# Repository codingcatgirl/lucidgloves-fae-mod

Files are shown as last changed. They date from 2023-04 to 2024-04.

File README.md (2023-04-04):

# LucidGloves Fae Mod

This repository contains files and instructions how to build the **LucidglovesFae Mod**, a mod of the
**[Lucidgloves Prototype 5](https://github.com/LucidVR/lucidgloves/tree/proto5) by Lucas VRTech**.

<p>
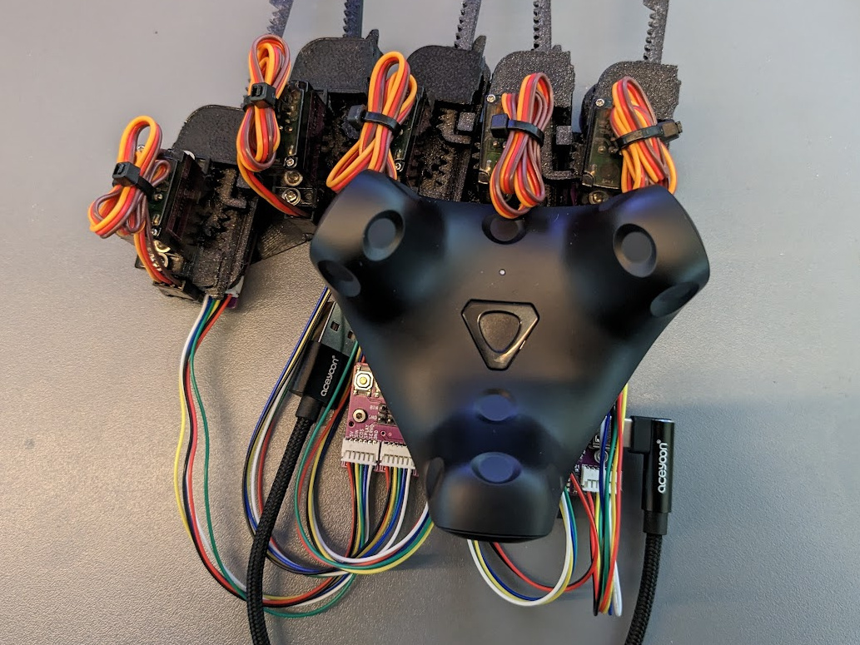
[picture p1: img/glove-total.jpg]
  
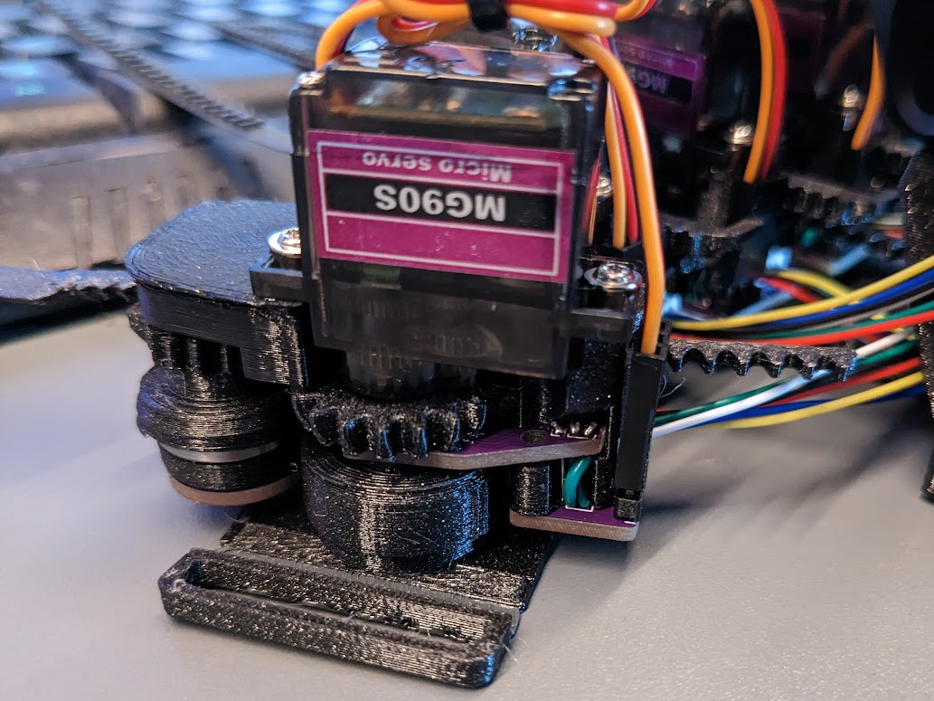
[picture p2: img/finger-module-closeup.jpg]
     
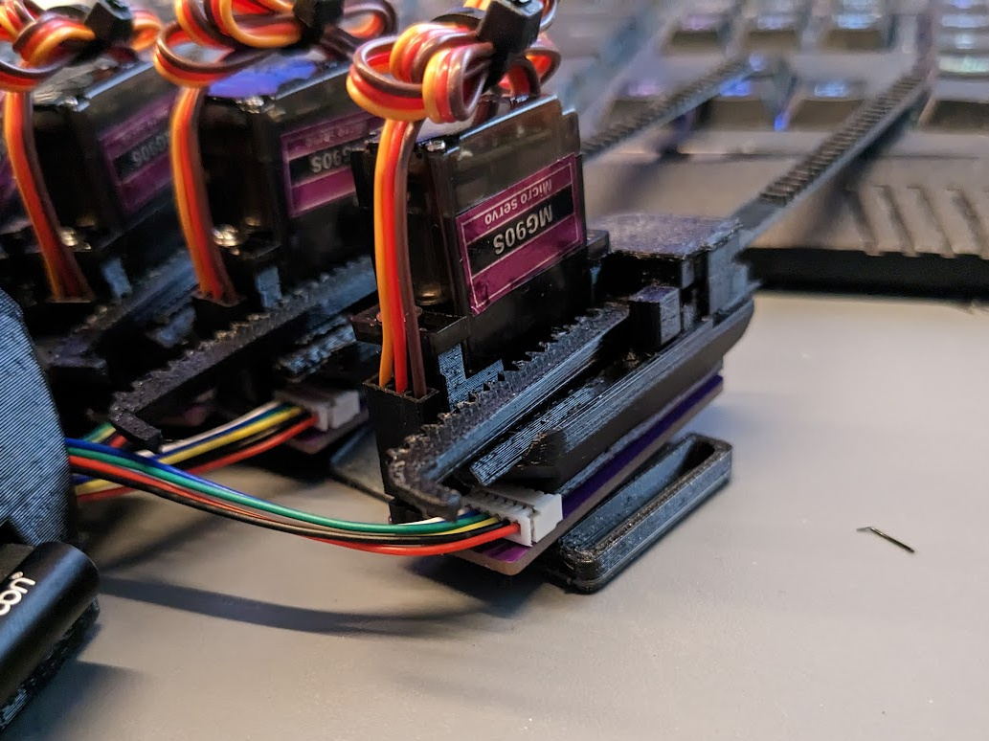
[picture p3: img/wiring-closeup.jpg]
  
</p>

<p>
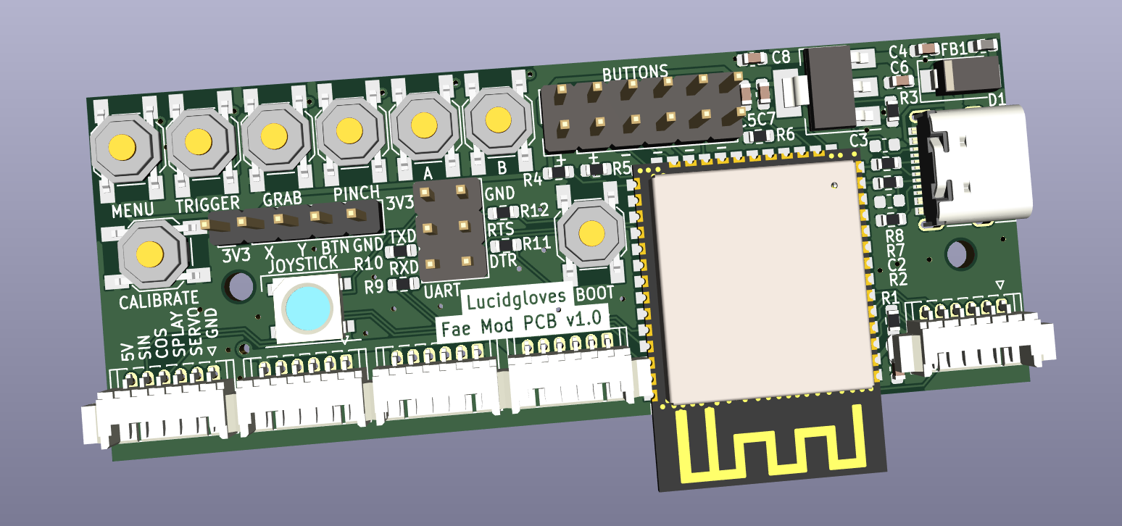
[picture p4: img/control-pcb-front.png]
  
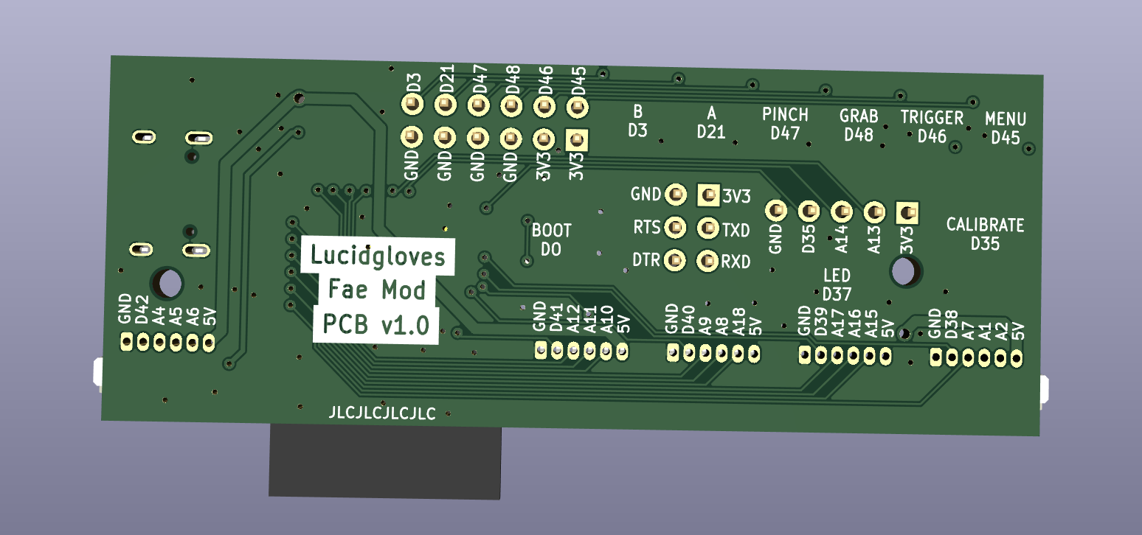
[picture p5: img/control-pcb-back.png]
  
</p>

The mod presently consists of 4 features that can, in theory, be used seperately:

* Custom PCBs to greatly simplify the wiring and provide a compact control PCB featuring an ESP32-S3 chip and 
  most notably no need for a multiplexer chip. With the files provided they can be ordered directly from
  [JLCPCB](https://jlcpcb.com/) including most of the assembly. 
* A modified sensor module that prints without supports and fits the new PCBs. It can also be used without the new PCBs.
* A new tracker mount that includes space for the control PCB. It can also be used without the new PCBs.
* A two-material version of the rigid mount, that allows you to print part of it with flexible filament (TPU) so it
  flexes more nicely where it needs to. It can be used without the other parts of this mod. It can also be printed using
  a non-multi-material printer. 

## Cost

The additional parts, including the custom PCBs and shipping, will set you back ~$30 per glove for 2 gloves, or 
$20 per glove for 4 gloves. The reason for the massive price difference is that JLCPCB manufactures PCBs in multiples
of five, so you will order at least 5 control PCBs. You can have them only assemble 2, but the price
difference would be about $1. For the finger PCBs, the price barely increases if you order enough for 20 fingers instead
of 10 fingers. So, simply put: You might as well order enough parts for 4 gloves, and split the cost with a friend :)

Keep in mind this comes on top of the cost for the other parts you need for prototype 5 anyway, but you will not need 
the ESP dev module or the multiplexer chip, which will save you about $6-$7 per glove. You will also not need additional
cables as they are all included. In my opinion, the reduced hassle alone is worth the cost.

At the time of writing this, the cost of parts to build the LucidGloves Fae Mod including 3D printing filament and
all parts, according to my calculations, comes down to ~$60 per glove for 2 gloves and ~$40 per glove for 4 gloves.

Don't forget that you will still need to buy a SteamVR tracker of your choice, a USB cable and a Powerbank for each
glove thogh, of course.  

## Important caveat

**The ESP32-S3 chip does not support BluetoothSerial. This means that, presently, the gloves can only
be connected using a wired USB connection.** The chip itself supports both Bluetooth Low Energy and WiFi for
communication, neither of these are currently implemented in the firmware or the 
[opengloves driver](https://github.com/LucidVR/opengloves-driver), though there seem to be plans to support
BLE for communication in the future.

If you're a developer and feel like implementing communication via WiFi/TCP/UDP or Bluetooth Low Energy in the
oopengloves driver and submit a pull request to it, i'm sure it would be appreciated by the community.
I don't have enough experience with software development on windows to do it myself. However, i am experienced
with firmware development and if someone added the support to the opengloves driver, i would probably be up to
implementing the other side of it for the firmware.

## Instructions

- [Ordering the parts needed](docs/ordering_parts.md)
- [3D Printing the modified parts](docs/3d_printing.md)
- [Assembling the modified parts](docs/assembly.md)
- [Modifying the firmware](docs/firmware.md)

## Contributing

Feedback is always welcome.

If you have questions that are about the specific of this mod, feel free to use the issue tracker. If you have questions
about the LucidGloves in general and assembly or setup steps that are not different for this mod, please stick to the 
official support channels of the original LucidGloves.

If you find an error somewhere or see a way to improve the documentation, feel free to open an issue or a pull request.

It sure would be nice if the instructions had some screenshots and images in then. If you feel like it, make some while
you follow along with the instructions and submit them to this repo, ideally using a pull request :)

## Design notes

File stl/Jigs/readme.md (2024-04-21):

# Soldering Jigs

## Prep
You should have the jst connectors soldered to your larger boards 

You will need one each of Jig 1 and Jig 2, and two of Jig 3.

Screw a spare of the larger board to Jig 1, then attach one of Jig 3 to the bottom so it will sit flat. You can use the raised part of Jig 3 to glue it to Jig 3 with something you can remove later, so you can take it apart if you need the board back.

## Step 1
Screw a smaller board into Jig 1. Drop some component legs into the holes, Jig 3 will act as a stop keeping them from falling all the way through. Solder them on, then trim them.

## Step 2
Screw the larger board to the module, then slip the legs we just soldered on into place, screw down the small board, and place upside-down in Jig 2. Solder the legs, then trim.

## Step 3
Place a hall sensor into the splay spot, so that it faces toward the center of the circle, away from the main body of the sensor. Place it onto Jig 3 and solder the legs, then trim. Save the legs for the next module. The sensor will protrude a tiny amount, this is intentional.

## Step 4
Place hall sensors into the Sin and Cos slots. Sin should face away from the center of the circle, towards the main body. Cos should face towards the center of the circle. Place the module into Jig 2 again, solder the legs, and trim. Save these legs seperately, they're shorter and therefore harder to work with, but the legs are super easy to drop on the floor so these will serve as spares.

## Step 5
Place a 3-pin header into a 3-pin connector. Jig 3 will make it easier to hold it in place while you tack one of the legs. Remove the connector and solder the header.

## You Are Done
Pat yourself on the back. Proceed to mechanical assembly

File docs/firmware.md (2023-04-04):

# Modifying the firmware

**Important:** Make sure you are using the newest version of the ESP32Servo library, or it will not work!

You need to open some files of the prototype 5 firmware and edit them as described here:

## _main.ino

**Remove** the following line:

```cpp
  pinMode(32, INPUT_PULLUP);
```

## input.ino

**Remove** these lines:

```cpp
  pinMode(PIN_MENU_BTN, INPUT_PULLUP);
  
  #if !TRIGGER_GESTURE
  pinMode(PIN_TRIG_BTN, INPUT_PULLUP);
  #endif
```

**Replace** this line:

```cpp
   return analogRead(UNMUX(pin));
```

with this line:

```cpp
   return analogRead(pin);
```

## lucidgloves-firmware.ino

Adjust the settings ot look like this. These lines are not all next to each other in the file, 
just find the corresponding lines and adjust the values.

**Important:** These are the settings for your right hand. If you are wiring up a left hand, you need to swap the values
pinky and thumb, and for index and ring.

Eagle-eyed viewers might notice that there is a WS2812 RGB LED on the board. The firmware defines a DEBUG_LED pin, but
doesn't use it. We are attaching the RGB LED to this pin. Of course, if the firmware eventually started using the
DEBUG_LED, it wouldn't work correctly with the WS2812 LED. If you feel like it, go ahead and implement both :)

```cpp
#define USING_SPLAY true
#define USING_MULTIPLEXER false

#define INVERT_A false
#define INVERT_B false
#define INVERT_JOY false
#define INVERT_MENU true
#define INVERT_CALIB false
#define INVERT_TRIGGER true
#define INVERT_GRAB false
#define INVERT_PINCH false

#define USING_FORCE_FEEDBACK true

#define PINS_MUX_SELECT   -1,  /*S0 pin*/ \
                          -1,  /*S1 pin*/ \
                          -1,  /*S2 pin*/ \
                          -1   /*S3 pin*/
#define MUX_INPUT -1

#define PIN_MENU_BTN  45
#define PIN_A_BTN     21
#define PIN_B_BTN      3
#define PIN_TRIG_BTN  46
#define PIN_GRAB_BTN  48
#define PIN_PNCH_BTN  47
#define PIN_CALIB     36

#define PIN_JOY_X     13
#define PIN_JOY_Y     14
#define PIN_JOY_BTN   35

#define DEBUG_LED     23  

#define PIN_PINKY      6
#define PIN_RING      10
#define PIN_MIDDLE    18
#define PIN_INDEX     15
#define PIN_THUMB      2

#define PIN_PINKY_SECOND    5
#define PIN_RING_SECOND    11
#define PIN_MIDDLE_SECOND   8
#define PIN_INDEX_SECOND   16
#define PIN_THUMB_SECOND    1

#define PIN_PINKY_SPLAY     4
#define PIN_RING_SPLAY     12
#define PIN_MIDDLE_SPLAY    9
#define PIN_INDEX_SPLAY    17
#define PIN_THUMB_SPLAY     7

#define PIN_PINKY_MOTOR    42
#define PIN_RING_MOTOR     41
#define PIN_MIDDLE_MOTOR   40
#define PIN_INDEX_MOTOR    39
#define PIN_THUMB_MOTOR    38
```

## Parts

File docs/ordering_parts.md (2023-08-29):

# Ordering the parts needed

## Parts needed

For each of these, remember that having 1-2 to spare can be very useful.

* 1× (per glove) **ESP32-S3-WROOM-1** ([AliExpress](https://www.aliexpress.com/item/1005004815894336.html))
  * If you order it somewhere else, make sure it definitely is the **S3** version, and that it does **not have an U**
    at the end (then it comes without an antenna).
  * Previously, the recommended module was the **ESP-S3-32S** by **Ai-thinker**, recommended because it is easier to solder
    because it doesn't have soldering pads on the bottom. However, this module got discontinued and soldering the pads on the
    bottom of the WROOM-module is optional, so this is now recommended instead.
* 10× (per glove) **JST 6 pin 1.25mm pitch right angle THT connector** ([AliExpress](https://www.aliexpress.com/item/1005004374200185.html))
  * Make sure you select the **right angle version** (called `curved needle` in the linked product) and 
    **6 pin version** (called `6P` in the linked product).
  * This seems to actually not be a connector from JST, but for some reason sellers on Aliexpress call it that anyway.
  * In theory, you can select other right-angled connectors with 6 pins and 1.25mm, but if you do make sure you are
    ordering the right cables for it as well.
  * (If you opt to have JLCPCB assemble these for you (see below), you will only need 5 of these per glove.)
* 5× (per glove) **JST 6pin 1.25mm pitch cable 10cm** ([AliExpress](https://www.aliexpress.com/item/1005002531804129.html)) 
  * Make sure you select the **6 pin versiom** (called `6P` in the linked product) and **10cm** (15cm is fine too).
* **2.54mm pitch pin headers** ([AliExpress](https://www.aliexpress.com/item/32758380907.html))
  * They are used to more easily connect buttons, joysticks and (should you ever need it) a programmer
    using jumpers. In theory, most of them are optional, but you need 3 pins per finger to connect the servo.
  * The AliExpress link here is merely an example but those will be plenty for even 10 gloves and more. You can find
    these everywhere and might even have some laying around still. Per glove you will need 38 pins, unless you chose to
    leave out some.
  * (If you opt to have JLCPCB assemble these for you (see below), you will only need 15 pins per glove.)
* 17× (per glove) **DIN912 M2×5 screws** ([AliExpress](https://www.aliexpress.com/item/759266313.html))
  * Similar screw will do. 4mm or 6mm will work as well.
  * Strictly speaking these are optional if you like hot gluing things.

You will **not** need the following parts from the original gloves: 

* ESP32-WROOM-32(U)
* CD74HC4067 Multiplexer

## PCBs

This is a guide on how to order the PCBs from JLCPCB. You can of course order them anywhere else if you want.

There are 3 different PCB that you will need to order. We start with the control PCB.

Create an account/sign into [JLCPCB.com](JLCPCB.com). Click on `Order now`. On the first page, do the following:

* Download [control_pcb.zip](../pcb/control_pcb.zip), and upload it usin the `Add gerber file` button.
* Set the `PCB Color` to one you like.
* Set the `Surface Finish` to `LeadFree HASL`, unless you are absolutely fine with lead. `ENIG` is also then option,
  very fancy but also very expensive. For some combinations of color and surface finish a warning will pop up and it
  will add a significant Special Process Fee. If that happens, you probably want to choose another color. 
* Set `Remove Order Number` to `Specify a location`.
* Switch on `PCB Assembly`.
* Double check that `PCBA Type` is set to `Economic`. If you can't select Economic, you need to choose another 
  combination of PCB Color and Surface finish.
* Click `Confirm`.

Click next until you reach the Upload for the BOM and CPL files.

* Download [the BOM file](../pcb/control_pcb_bom.csv) and [the CPL file](../pcb/control_pcb-top-pos.csv) and upload
  them respectively.
* Click `Process BOM & CPL`.

You are now on the page where you can review the parts that will be put in the PCB.

* Parts that are marked as `Extended` instead of `Basic` cost an extra fee. You can save money by leaving out some
  of them and acquiring and soldering them on yourself. 
  * This guide recommends and assumes that you leave out the pin headers and connectors, get those from AliExpress (see 
    below) and solder them on yourself because they are easy to solder and having them assembled would cost $10 more.
  * For this, untick the checkboxes of the Lines that say `FINGER1`, `FINGER2`, `FINGER3`, `FINGER4`, `FINGER5`, `UART/PROG`,
    `JOYSTICK` and `BUTTONS`. In total, you should unselect 8 checkboxes.
  * You can decide to leave these parts in and have them assembled if it's worth the additional cost to you. The
    selected connectors should fit the cables, but it has not been tested.
* Click `Next`. There will be a warning telling you that there is one part that can only be assembled using Standard
  assembly. 
  * This is the ESP chip. This part cannot be assembled using Economic Assembly due to temperature restrictions. 
    In the past, this has not been an issue. Apparently it is possible to contact JLCPCB support and ask them to unlock
    this part for Economc Assembly. This guide recommends and assumes that you will get this part from AliExpress (see
    below) and solder it yourself. 
  * Choose `Do not place this part`. Do **not** switch to Standard PCBA.
* Click `Next` again. There will be another, similar warning, that there are some unselected parts. 
  * Again, choose `Do not place`.

You are now on a page that shows you a preview of the assembly. 

* Some parts will not be in the right position. This is fine since this is only a preview and JLCPCB will correct the
  placement after you placed your order.
* Click `Next`.

You are now on a summary page.

* You should see a total price of around $27. If not, double check that you did everything right.
* For Product Description, you have to select what applies, usually DIY should do.
* Click `Save to Cart`.

Repeat these steps with [top_pcb.zip](../pcb/top_pcb.zip) and [bottom_pcb.zip](../pcb/bottom_pcb.zip), but:

* Make sure that you select the right quantity. You need one of each per finger. 
* Do not set `Remove Order Number`.
* Do not enable assembly.

You can experiment with the quantities of the PCBs in your cart to see how it affects the price. 

* Don't be confused that the top and bottom PCBs don't have the same price in your cart, this is due to special offers 
  that apply only once per order.
* If you make two gloves, it could still be useful to order 15 top and bottom PCBs each so you have a few spares, 
  if it's worth the cost to you.
* You can, in theory, also ask them to only assemble 2 control PCBs instead of all 5. This guide does not recommend 
  this, as it barely saves you any money, and it's good to have spare PCBs just in case.

If you are happy, go to checkout. Pay attention to the following two things:

* On the payment page, there will be a select the $9 coupon for SMT Assembly. Don't forget to select that one.
* There's an extra fee if you use PayPal.

Congratulatios, you're done with the PCBs!

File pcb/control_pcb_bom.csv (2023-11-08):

Comment | Designator | Footprint | LCSC
1uF | C1 | Capacitor_SMD:C_0603_1608Metric | C15849
10uF | C4,C5 | Capacitor_SMD:C_0603_1608Metric | C96446
100nF | C6,C7,C8 | Capacitor_SMD:C_0603_1608Metric | C14663
SS54 | D1 | Diode_SMD:D_SMA | C22452
WS2812 | D2 | LED_SMD:LED_WS2812B_PLCC4_5.0x5.0mm_P3.2mm | C2920042
3A 0603 | FB1 | Inductor_SMD:L_0603_1608Metric | C113030
USB_C_Receptacle_USB2.0 | J1 | Connector_USB:USB_C_Receptacle_G-Switch_GT-USB-7010ASV | C2760486
JOYSTICK | J13 | Connector_PinHeader_2.54mm:PinHeader_1x05_P2.54mm_Vertical | C5156614
BUTTONS | J16 | Connector_PinHeader_2.54mm:PinHeader_2x06_P2.54mm_Vertical | C706896
UART/PROG | J2 | Connector_PinHeader_2.54mm:PinHeader_2x03_P2.54mm_Vertical | C706893
FINGER1 | J3 | Connector_Hirose:Hirose_DF13-06P-1.25DS_1x06_P1.25mm_Horizontal | C2845539
FINGER2 | J4 | Connector_Hirose:Hirose_DF13-06P-1.25DS_1x06_P1.25mm_Horizontal | C2845539
FINGER3 | J5 | Connector_Hirose:Hirose_DF13-06P-1.25DS_1x06_P1.25mm_Horizontal | C2845539
FINGER4 | J6 | Connector_Hirose:Hirose_DF13-06P-1.25DS_1x06_P1.25mm_Horizontal | C2845539
FINGER5 | J7 | Connector_Hirose:Hirose_DF13-06P-1.25DS_1x06_P1.25mm_Horizontal | C2845539
10k | R1,R4,R5,R6 | Resistor_SMD:R_0603_1608Metric | C25804
5k1 | R2,R3 | Resistor_SMD:R_0603_1608Metric | C23186
0R | R7,R8 | Resistor_SMD:R_0603_1608Metric | C21189
100 | R9,R10,R11,R12 | Resistor_SMD:R_0603_1608Metric | C22775
MENU | SW1 | Button_Switch_SMD:SW_SPST_SKQG_WithStem | C318884
TRIGGER | SW2 | Button_Switch_SMD:SW_SPST_SKQG_WithStem | C318884
GRAB | SW3 | Button_Switch_SMD:SW_SPST_SKQG_WithStem | C318884
PINCH | SW4 | Button_Switch_SMD:SW_SPST_SKQG_WithStem | C318884
A | SW5 | Button_Switch_SMD:SW_SPST_SKQG_WithStem | C318884
B | SW6 | Button_Switch_SMD:SW_SPST_SKQG_WithStem | C318884
CALIB. | SW7 | Button_Switch_SMD:SW_SPST_SKQG_WithStem | C318884
BOOT | SW8 | Button_Switch_SMD:SW_SPST_SKQG_WithStem | C318884
ESP32-S3-WROOM-1 | U1 | Espressif:ESP32-S3-WROOM-1 | C2913197
AMS1117-3.3 | U2 | Package_TO_SOT_SMD:SOT-223-3_TabPin2 | C6186

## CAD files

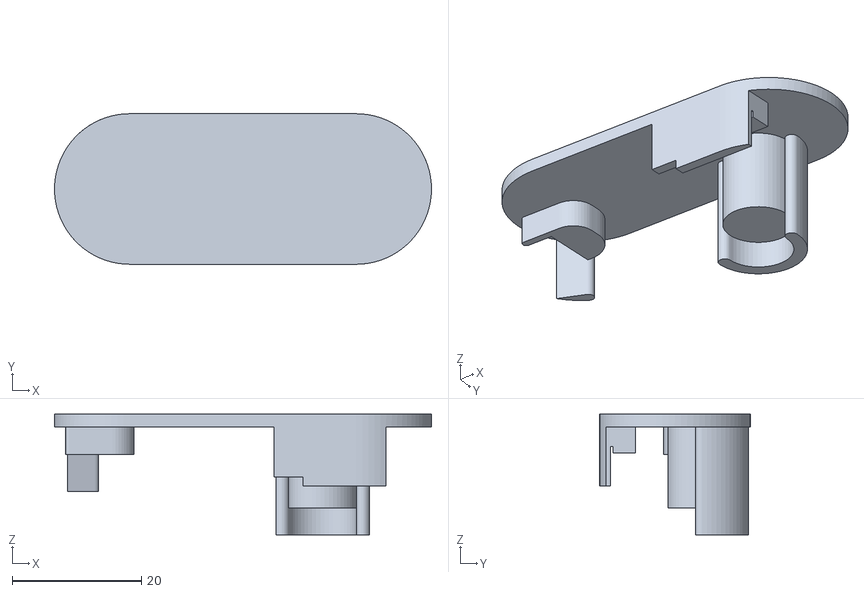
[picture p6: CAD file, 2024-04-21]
stl/Jigs/Jig 2.stl
58.4 x 23.3 x 18.7

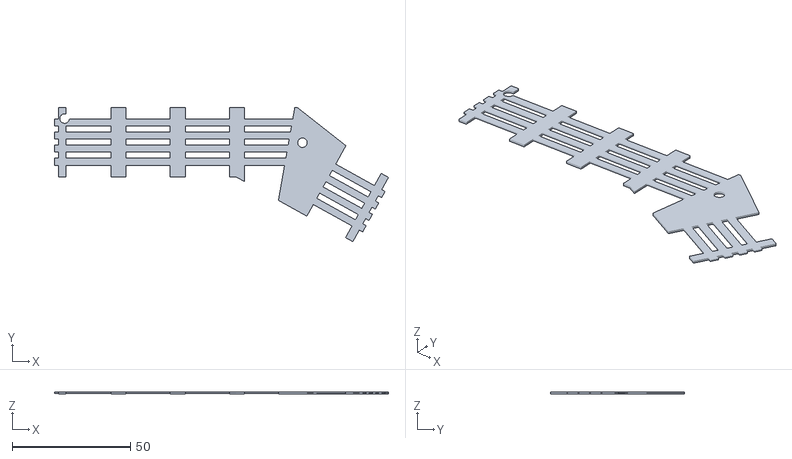
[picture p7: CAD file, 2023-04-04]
stl/RigidMount_Splay_v3_FaeMod_Flex_v1.0.stl
141.0 x 56.7 x 0.9

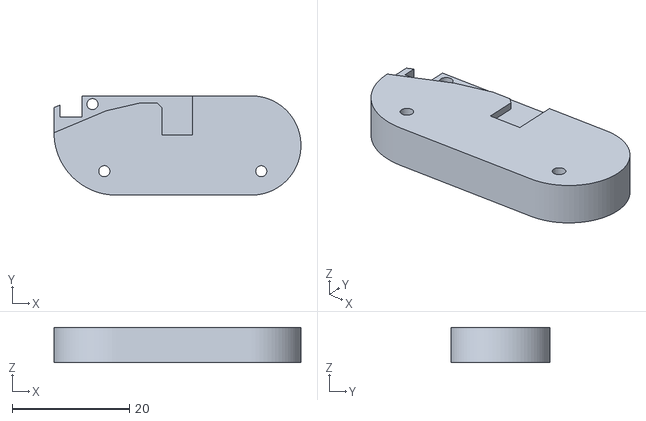
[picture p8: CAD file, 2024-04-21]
stl/Jigs/Jig 1.stl
42.2 x 17.0 x 6.00

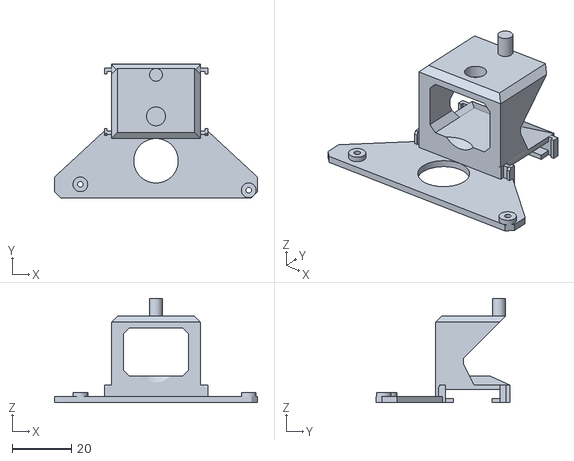
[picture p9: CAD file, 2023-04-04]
stl/TrackerMount_FaeMod_v1.0.stl
68.5 x 45.1 x 35.2

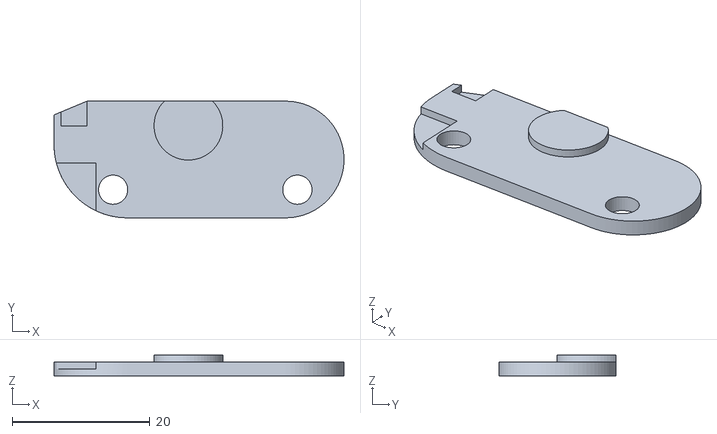
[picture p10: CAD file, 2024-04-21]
stl/Jigs/Jig 3.stl
42.2 x 17.0 x 3.00

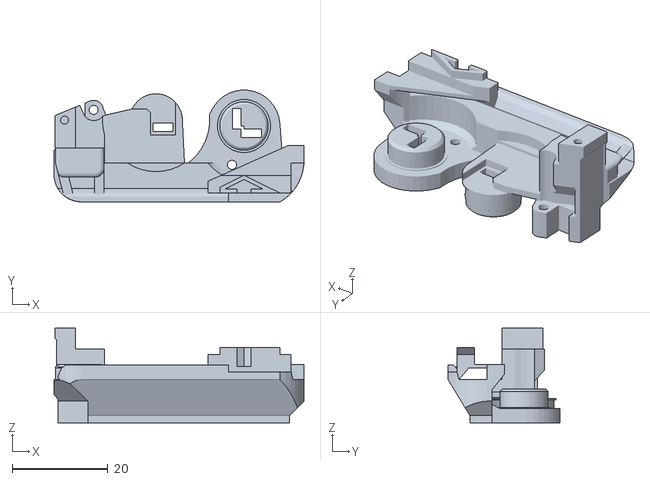
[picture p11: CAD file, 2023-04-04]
stl/SensorHousing_v5.9_FaeMod_v1.0.stl
52.1 x 23.3 x 19.7

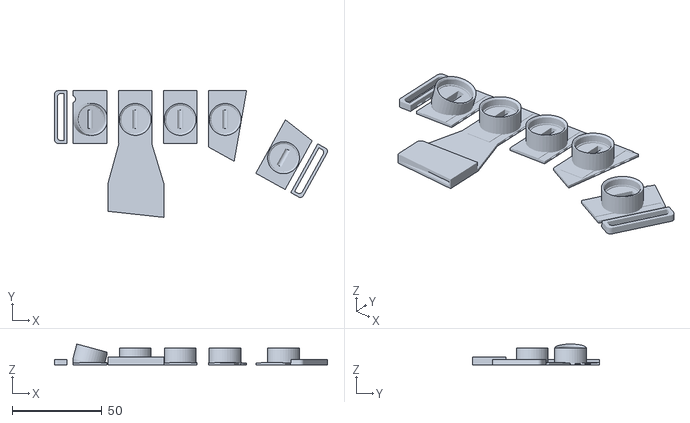
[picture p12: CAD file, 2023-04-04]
stl/RigidMount_Splay_v3_FaeMod_Rigid_v1.0.stl
151.8 x 70.5 x 11.6

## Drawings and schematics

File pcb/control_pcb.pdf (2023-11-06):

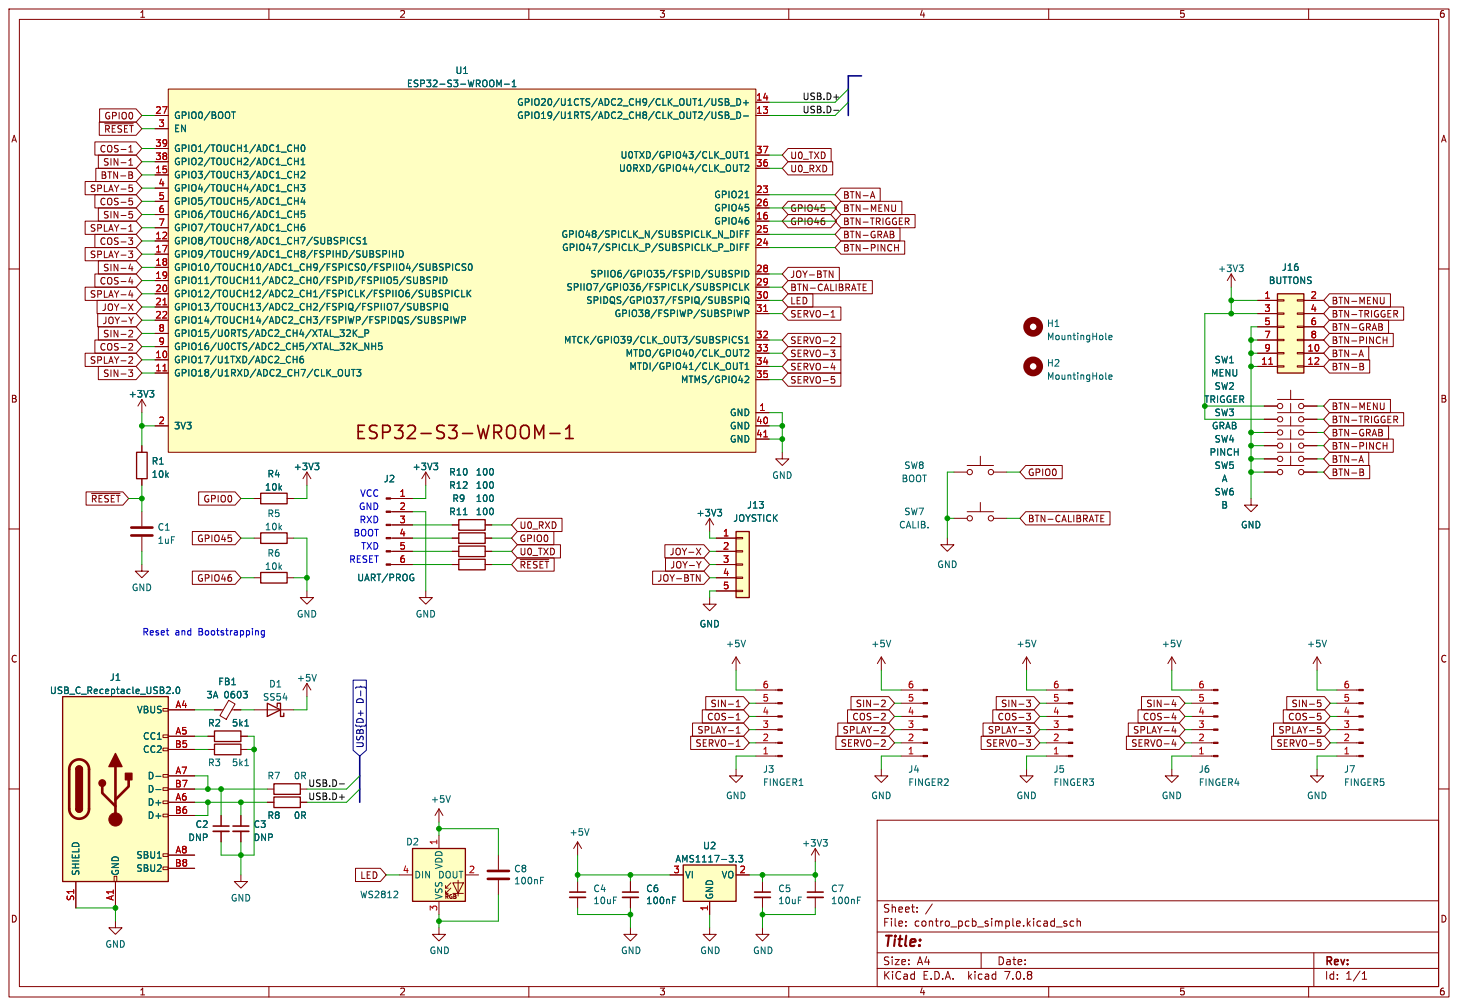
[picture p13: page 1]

JOY-Y COS-1 SIN-4 ~{RESET} BTN-B

SERVO-1 BTN-CALIBRATE USB{D+ D-} LED

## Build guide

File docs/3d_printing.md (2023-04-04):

# 3D Printing the modified parts

## Modified Sensor Housing

* Download  [Modified Sensor Housing STL](../stl/SensorHousing_v5.9_FaeMod_v1.0.stl).
* No supports or anything similar needed. 
* In order for bridging helpers to work correctly, you need to print a layer height of 0.15mm or lower and 3 outer
  perimeters or more. 
* At that point, infill won't matter and can be pretty low.
* After printing, remove the two tiny bridges at the end of the module holding up the "lip".

## New Tracker Mount

* Download [New Tracker Mount STL](../stl/TrackerMount_FaeMod_v1.0.stl).
* No supports or anything similar needed.
* In order for bridging helpers to work correctly, you need to print a layer height of 0.2mm or lower.
* 2-3 perimeters should be enough.
* Infill doesn't matter.

## Two-Material flexible version of the rigid mount

You will need flexible filament for this (duh). For example, this was tested with Fiberlogy Fiberflex 40D. 

* Download [the rigid part](../stl/RigidMount_Splay_v3_FaeMod_Rigid_v1.0.stl) and 
  [the flexible part](../stl/RigidMount_Splay_v3_FaeMod_Flex_v1.0.stl) of the modified rigid mount.
* There are many guides online on how to print multi material if your printer has only one nozzle and you can look 
  for more detailed instructions for your slicer/printer. However, here's a brief summary:
  * Tell your slicer that your printer has two hot ends (even if it doesn't). 
  * Import the two STLs into your slicer, make sure it detects it as two parts of the same object for multi material
    printing.
  * Set the filaments correctly for the flexible and rigid part.
  * Make sure your printer supports `M600` or a similar print pause/filament change G-Code command.
  * Set `M600` (or whatever command your printer understands) as the custom Filament Change/Tool Change G-Code.
    In PrusaSlicer/SuperSlicer, you find this in the Custom G-Code section of your Printer profile. In Cure, there
    is an Extension called `Post Processing` that you can use to add a custom G-Code script.
* Set the layer height to 0.25mm for the bottom 1mm or the entire print. You can set it lower, but then you'll have
  to change the filament more often.
* If you have done it correctly, there should only be 4 manual filament changes for the entire print.
* No supports needed, infill doesn't matter, 2-3 perimeters recommended.
* Good luck!

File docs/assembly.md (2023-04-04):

# Assembling the modified parts

Please read the entire instructions before starting the assembly, so you know what's coming. Also, 
read the entirety of each step again before starting that step.

## Step 1: Assemble the bottom PCB

The bottom PCB is the bigger one that is not assembled. 

Solder one of the right-angled connectors onto it. Make sure it's on the top side. When you hold the PCB on the bottom
of the printed sensor housing, the connector should fit into the small space that is there for it.

Now, use a multimeter to check that there are no shorts between the connector contacts. **Always do this when this
guide tells you to**, or you **will** inevitably run into trouble fixing it if you find a short later.

Cut off 3-pin piece of the 2.54mm pitch pin header strip and solder it on as well.

Repeat for all the bottom PCBs.

## Step 2: Assemble the control PCB.

The control PCB is the biggest one that is already mostly assembled.

Solder the ESP-S3-32S module in the place where it belongs. Make sure all the contacts are connected and that there are
no shorts. Don't worry about the exposed contacts in the middle of the part. This is just in case someone smart finds
a way to put the original Espressif module here (if that's you, my head is off to you for presumably having a reflow
oven, also thanks for reading this guide even though you probably don't need it).

Populate the BUTTONS and JOYSTICK pin header slots. The PROG/UART pin header slot can be populated as well, but you can
skip it if you don't feel like it.

Now, take one of the cables that connect to the connectors. Plug it into one of your bottom PCBs. Check which wire color
corresponds to which of the labels (5V, SIN, COS, etc…) on the board. 

Now, put in one of the connectors without soldering it on yet. Make sure that if you plugged the cable in it, the colors match the labels here in
the same way. This is to check if the connector on the end of your cable is the right way around. If the labels
**don't** match, they should match if you put the connector on the other side of the PCB. Solder it on the correct side,
then solder on all the other connectors the same way.

Check for 

Repeat for all control PCBs.

## Step 3: Attach the top PCB

Take one of the top PCBs (kinda L-shaped) and try to fit it into its slot. Note how it covers the hole for the splay
hall effect sensor and the +, - and S labels next to the 3 holes for the legs of the hall effect sensor. 

Remove the PCB and stick the hall sensor into the hole in the right orientation. If needed, check for the pinout of the
sensor online. Make sure the sensor body does not stick out of the other side. Fit the PCB on top of it again.

Do not solder on the sensor yet. Instead, cut off the sensor legs so that a bit of them are still sticking out. You need
to cut off 13-14 mm at least. Keep these, you will need them. (If this is the second time you are doing this, you can
clip the sensor legs later because you should have enough leg clipping lying around.)

Stick the legs into the 3 other holes in the PCB that will connect the top PCB to the bottom pcb. Solder them in place.
If needed, you can remove the PCB for this.

Use your multimeter to check that there are no shorts between the 3 leads.

Put the PCB back if you removed it. Now, solder the sensor legs in place. Make sure the sensor is facing the right way
and is not sticking out on the bottom.

Now, use your multimeter to again check that there are no shorts between the 3 leads. You can measure it at the 
connector or directly at the sensor. Don't worry if your multimeter now says the leads are connected with some 
resistance. This is normal for the hall sensor. As long as there is not nearly zero resistance, everything is fine. If 
you want to be extra sure, measure the resistance between the legs of a hall sensor directly and compare.

Use one of the M2 screws to fix the PCB in place. 

## Step 4: Attach the bottom PCB

Use the same strategy as for the top PCB to determine the right orientation for the sin/cos hall sensors. Fit the
bottom PCB onto them, and also onto the leads that come of your top PCB that will connect it to the bottom PCB.

Solder on each sensor seperately as well as the connector to the top PCB. Then, use your multimeter to check for shorts
again. For completeness's sake, you can also check for this at the 6 pin connector.

Now, use two of the M2 screws to fix the PCB in place.

Repeat Step 3 and Step 4 for every finger module. 

## Step 5: Finger module assembly

Follow the original Prototype 5 instructions to assemble the finger modules. In the end, plug in the servo into the pin 
header. Note that the brown wire should connect to the pin labeled GND. 

Congratulations, your finger modules are ready!

## Step 6: Final assembly

Mount all the finger modules to the hand mount.

Attach your tracker to the tracker mount. Mount the control PCB to the tracker mount using two M2 screws.

Plug all the wires into the finger modules and connect them to the PCB. One of the wires can fit through the hole in
the tracker mount. 

Congratulations, you are done!

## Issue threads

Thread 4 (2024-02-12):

BOM fiel

Thekalihacker, 2024-02-12:
JBLPCB gave me a message saying that the C2 and C3 are not listed in the BOM file, and indeed in the preview, the two capacitators don't show up. Is this on purpose, or is the BOM file just wrong? If it is, what type capacitators should I put in the file?

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

codingcatgirl, 2024-02-13:
DNP = Do Not Place

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

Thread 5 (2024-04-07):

Strap mount too weak

DieKatzchen, 2024-04-07:
The parts at the ends where the strap hooks on don't have enough grip on the PLU to stay on and tear off. Those parts should be merged with the mount points next to them for added strength.

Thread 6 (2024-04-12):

Control PCB CPL missing from github

MoMoiin, 2024-04-12:
As the title states  the Control pcb Cpl file is not on GitHub or is inaccessible

codingcatgirl, 2024-04-12:
no it's not. it's literally right there in the PCB folder and it even has
CPL in its name.

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

MoMoiin, 2024-04-12:
Misread it, Sorry.

Closed 2024-04-12.

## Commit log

2023-04-04 add PCBs and part ordering instructions
    [control_pcb_bom.csv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]
2023-04-04 add printing instructions and STLs
    [RigidMount_Splay_v3_FaeMod_Flex_v1.0.stl, RigidMount_Splay_v3_FaeMod_Rigid_v1.0.stl, SensorHousing_v5.9_FaeMod_v1.0.stl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]
2023-04-04 update control PCB
2023-04-04 fix typo in tracker mount download link
2023-04-04 add assembly docs
2023-04-04 add note on ESP32Servo version
2023-04-04 add images of control pcb
2023-04-19 fix pin header partnumbers in bom
    [control_pcb_bom.csv]
2023-08-29 Update ordering_parts.md
    recomment ESP32-S3-WROOM-1 module, as the Ai-thinker module got discontinued (fixed #1)
2023-11-06 v1.1… fix silkscreen on uart header and add schematic pdf
2023-11-08 improve silkscreen a tiny bit
2023-11-08 remove parts from bom that are not placed, choose cheaper ESP32-S3
    [control_pcb_bom.csv]
2024-04-21 Create Jigs
    Some jigs I created to make soldering easier
    [Jig 1.stl, Jig 2.stl, Jig 3.stl]
